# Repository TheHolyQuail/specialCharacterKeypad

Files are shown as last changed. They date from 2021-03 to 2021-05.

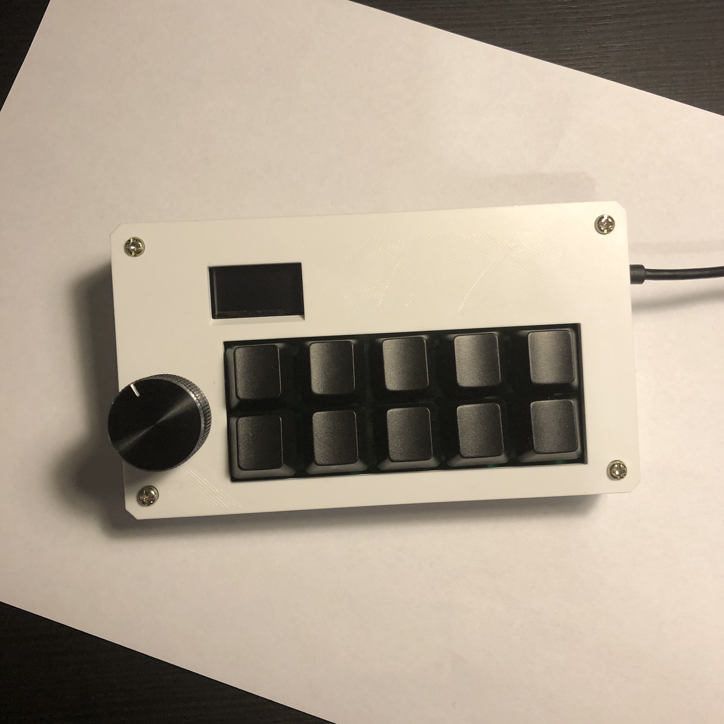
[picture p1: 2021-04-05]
images/keypad with white PLA case.jpg

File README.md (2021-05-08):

# specialCharacterKeypad
This project is a custom keypad using 10 Cherry MX keys as input, a potentiometer to change key values, and 128x64 OLED screen based key value readout all powered by the Raspberry Pi Pico. 
It is focused on allowing quick access to common symbols and letters used in math and science that are not present on the standard US keyboard.

The keypad CAD and ECAD were designed in Fusion 360 and the RP2040 is programed in Curcuitpython taking advantage of the libraries: time, busio, board, displayio, adafruit_displayio_ssd1306 (since the OLED used is based on the ssd1306), adafruit_imageload, math, digitalio, usb_hid, and parts of adafruit_hid.

The custom code is split into two files code.py which contains the loop and keyboard state control and typeSym.py which houses the functions used to send keystrokes to the host computer.

More a more detailed descriptions and assembly/programming instructions are availible on maker.io (link: https://www.digikey.com/en/maker/projects/multifunction-programmable-keypad-made-with-rp2040/5fb464c75f3c4db2a58f450f1997c600)

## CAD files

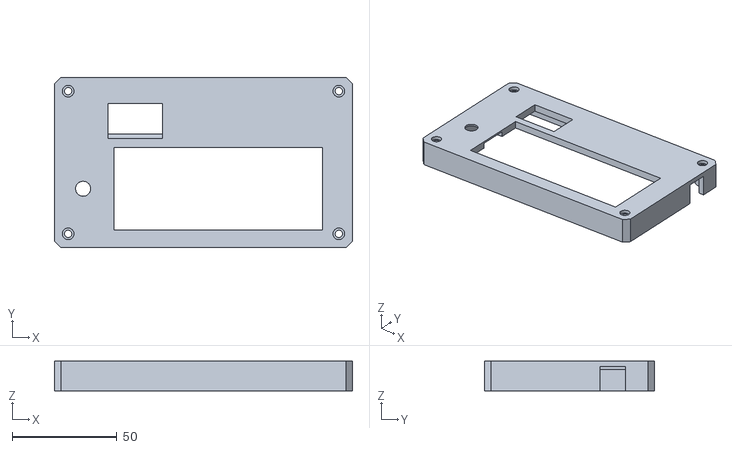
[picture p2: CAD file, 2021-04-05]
3D printable files/shell top V2.stl
142.0 x 81.0 x 14.1

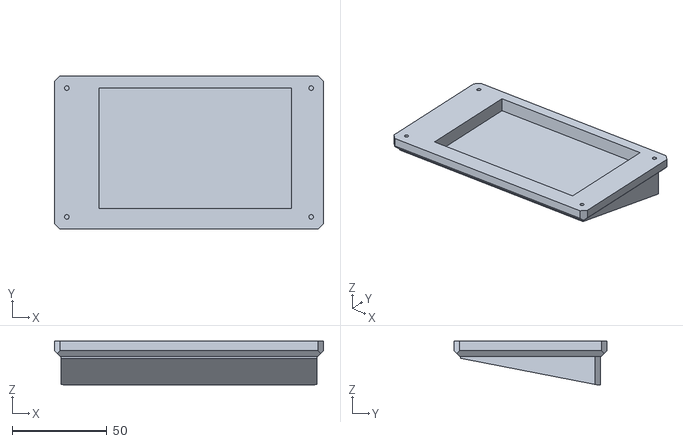
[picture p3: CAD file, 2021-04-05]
3D printable files/shell bottom V2.stl
142.0 x 81.0 x 23.0

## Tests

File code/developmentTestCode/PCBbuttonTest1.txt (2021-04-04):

# libraries for display and pin control
import os
import time
import busio
import board
import displayio
import terminalio
import adafruit_displayio_ssd1306
import adafruit_imageload

# libraries for USB HID
import digitalio
import usb_hid
from adafruit_hid.keyboard import Keyboard
from adafruit_hid.keycode import Keycode
from adafruit_hid.keyboard_layout_us import KeyboardLayoutUS

# library for potentiometer
import analogio

### keyboard and button setup ##############################
# creating keyboard
Keyboard = Keyboard(usb_hid.devices)
Layout = KeyboardLayoutUS(Keyboard)

# declaring button pins
btn0_pin = board.GP15
btn1_pin = board.GP5
btn2_pin = board.GP4
btn3_pin = board.GP3
btn4_pin = board.GP2
btn5_pin = board.GP14
btn6_pin = board.GP13
btn7_pin = board.GP12
btn8_pin = board.GP11
btn9_pin = board.GP10

# setting pin settings
btn0 = digitalio.DigitalInOut(btn0_pin)
btn0.direction = digitalio.Direction.INPUT
btn0.pull = digitalio.Pull.UP

btn1 = digitalio.DigitalInOut(btn1_pin)
btn1.direction = digitalio.Direction.INPUT
btn1.pull = digitalio.Pull.UP

btn2 = digitalio.DigitalInOut(btn2_pin)
btn2.direction = digitalio.Direction.INPUT
btn2.pull = digitalio.Pull.UP

btn3 = digitalio.DigitalInOut(btn3_pin)
btn3.direction = digitalio.Direction.INPUT
btn3.pull = digitalio.Pull.UP

btn4 = digitalio.DigitalInOut(btn4_pin)
btn4.direction = digitalio.Direction.INPUT
btn4.pull = digitalio.Pull.UP

btn5 = digitalio.DigitalInOut(btn5_pin)
btn5.direction = digitalio.Direction.INPUT
btn5.pull = digitalio.Pull.UP

btn6 = digitalio.DigitalInOut(btn6_pin)
btn6.direction = digitalio.Direction.INPUT
btn6.pull = digitalio.Pull.UP

btn7 = digitalio.DigitalInOut(btn7_pin)
btn7.direction = digitalio.Direction.INPUT
btn7.pull = digitalio.Pull.UP

btn8 = digitalio.DigitalInOut(btn8_pin)
btn8.direction = digitalio.Direction.INPUT
btn8.pull = digitalio.Pull.UP

btn9 = digitalio.DigitalInOut(btn9_pin)
btn9.direction = digitalio.Direction.INPUT
btn9.pull = digitalio.Pull.UP

### potentiometer setup ####################################
pot = analogio.AnalogIn(board.GP26)

def get_voltage(pin):
    #return (pin.value * 3.3) / 65536
    return (pin.value)/100

### display setup ##########################################
WIDTH = 128
HEIGHT = 64
CENTER_X = int(WIDTH/2)
CENTER_Y = int(HEIGHT/2)

displayio.release_displays()

SDA = board.GP8
SCL = board.GP9
i2c = busio.I2C(SCL, SDA)

if(i2c.try_lock()):
    print("i2c.scan(): " + str(i2c.scan()))
    i2c.unlock()
print()

display_bus = displayio.I2CDisplay(i2c, device_address=60)
display = adafruit_displayio_ssd1306.SSD1306(display_bus, width=WIDTH, height=HEIGHT)

"""
“displayio” drivers will also work with CircuitPython to display error messages
and other output to the display when the user code is not using it.
"""
print("Raspberry Pi Pico/CircuitPython ")
print("SSD1306 displayio (adafruit_displayio_ssd1306)")
time.sleep(.5)

#print((get_voltage(pot)))
#time.sleep(.5)

#================================================
"""
bitmap1, palette = adafruit_imageload.load("/bitmaps/bitmapTest2.bmp",
                                         bitmap=displayio.Bitmap,
                                         palette=displayio.Palette)
bitmap2, palette = adafruit_imageload.load("/bitmaps/cp_sprite_sheet.bmp",
                                         bitmap=displayio.Bitmap,
                                         palette=displayio.Palette)
"""
# 0:, 1:, 2:, 3:, 4:, 5:, 6:, 7:, 8:, 9:
arrows, palette = adafruit_imageload.load("/bitmaps/arrows.bmp",
                                         bitmap=displayio.Bitmap,
                                         palette=displayio.Palette)

# 0:, 1:, 2:, 3:, 4:, 5:, 6:, 7:, 8:, 9:
logic1, palette = adafruit_imageload.load("/bitmaps/logicSymbols1.bmp",
                                         bitmap=displayio.Bitmap,
                                         palette=displayio.Palette)

# 0:, 1:, 2:, 3:, 4:, 5:, 6:, 7:, 8:, 9:
logic2, palette = adafruit_imageload.load("/bitmaps/logicSymbols2.bmp",
                                         bitmap=displayio.Bitmap,
                                         palette=displayio.Palette)

# 0:, 1:, 2:, 3:, 4:, 5:, 6:, 7:, 8:, 9:
mathOperators1, palette = adafruit_imageload.load("/bitmaps/mathCommonOperators1.bmp",
                                         bitmap=displayio.Bitmap,
                                         palette=displayio.Palette)

# 0:, 1:, 2:, 3:, 4:, 5:, 6:, 7:, 8:, 9:
mathSymbols1, palette = adafruit_imageload.load("/bitmaps/mathCommonSymbols1.bmp",
                                         bitmap=displayio.Bitmap,
                                         palette=displayio.Palette)

# 0:, 1:, 2:, 3:, 4:, 5:, 6:, 7:, 8:, 9:
mathSymbols2, palette = adafruit_imageload.load("/bitmaps/mathCommonSymbols2.bmp",
                                         bitmap=displayio.Bitmap,
                                         palette=displayio.Palette)

# Create a TileGrid to hold the bitmap
#tile_grid1 = displayio.TileGrid(bitmap1, pixel_shader=palette)
#tile_grid2 = displayio.TileGrid(bitmap2, pixel_shader=palette)

arrowsGrid = displayio.TileGrid(arrows, pixel_shader=palette)
logicGrid1 = displayio.TileGrid(logic1, pixel_shader=palette)
logicGrid2 = displayio.TileGrid(logic2, pixel_shader=palette)
mOperatorGrid = displayio.TileGrid(mathOperators1, pixel_shader=palette)
mSymbolGrid1 = displayio.TileGrid(mathSymbols1, pixel_shader=palette)
mSymbolGrid2 = displayio.TileGrid(mathSymbols2, pixel_shader=palette)

# Create a Group to hold the TileGrid
group = displayio.Group(max_size=5)

# Add the TileGrid to the Group
#group.append(tile_grid2)
group.append(arrowsGrid)

# Add the Group to the Display
display.show(group)

# Loop forever so you can enjoy your image
while True:
    time.sleep(0.1)
    if not btn0.value:
        # type "aa"
        Keyboard.press(Keycode.A)
        time.sleep(0.1)
        Keyboard.release(Keycode.A)
        time.sleep(0.1)
        Keyboard.press(Keycode.A)
        time.sleep(0.1)
        Keyboard.release(Keycode.A)
        
    if not btn1.value:
        # type "a"
        Keyboard.press(Keycode.A)
        time.sleep(0.1)
        Keyboard.release(Keycode.A)
        # change display to bitmap one
        group.pop(0)
        group.append(logicGrid1)
        display.show(group)
        #print((get_voltage(pot)))
        
    if not btn2.value:
        # type "∞"
        Keyboard.press(Keycode.ALT, Keycode.KEYPAD_TWO, Keycode.KEYPAD_THREE, Keycode.KEYPAD_SIX)
        time.sleep(0.1)
        Keyboard.release(Keycode.ALT, Keycode.KEYPAD_TWO, Keycode.KEYPAD_THREE, Keycode.KEYPAD_SIX)
        
        # change display to bitmap two
        group.pop(0)
        group.append(logicGrid2)
        display.show(group)
        
    if not btn3.value:
        # type "b"
        Keyboard.press(Keycode.B)
        time.sleep(0.1)
        Keyboard.release(Keycode.B)
        
    if not btn4.value:
        # type "c"
        Keyboard.press(Keycode.C)
        time.sleep(0.1)
        Keyboard.release(Keycode.C)
        
    if not btn5.value:
        # type "d"
        Keyboard.press(Keycode.D)
        time.sleep(0.1)
        Keyboard.release(Keycode.D)
        
    if not btn6.value:
        # type "e"
        Keyboard.press(Keycode.E)
        time.sleep(0.1)
        Keyboard.release(Keycode.E)
        
    if not btn7.value:
        # type "f"
        Keyboard.press(Keycode.F)
        time.sleep(0.1)
        Keyboard.release(Keycode.F)
        
    if not btn8.value:
        # type "g"
        Keyboard.press(Keycode.G)
        time.sleep(0.1)
        Keyboard.release(Keycode.G)
        
    if not btn9.value:
        # type "h"
        Keyboard.press(Keycode.H)
        time.sleep(0.1)
        Keyboard.release(Keycode.H)

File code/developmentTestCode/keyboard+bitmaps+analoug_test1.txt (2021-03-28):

# libraries for display and pin control
import os
import time
import busio
import board
import displayio
import terminalio
import adafruit_displayio_ssd1306
import adafruit_imageload

# libraries for USB HID
import digitalio
import usb_hid
from adafruit_hid.keyboard import Keyboard
from adafruit_hid.keycode import Keycode
from adafruit_hid.keyboard_layout_us import KeyboardLayoutUS

# library for potentiometer
import analogio

### keyboard and button setup ##############################
Keyboard = Keyboard(usb_hid.devices)
Layout = KeyboardLayoutUS(Keyboard)

btn1_pin = board.GP14

btn1 = digitalio.DigitalInOut(btn1_pin)
btn1.direction = digitalio.Direction.INPUT
btn1.pull = digitalio.Pull.DOWN

btn2_pin = board.GP15

btn2 = digitalio.DigitalInOut(btn2_pin)
btn2.direction = digitalio.Direction.INPUT
btn2.pull = digitalio.Pull.DOWN

### potentiometer setup ####################################
pot = analogio.AnalogIn(board.GP26)

def get_voltage(pin):
    #return (pin.value * 3.3) / 65536
    return (pin.value)/100

### display setup ##########################################
WIDTH = 128
HEIGHT = 64
CENTER_X = int(WIDTH/2)
CENTER_Y = int(HEIGHT/2)

displayio.release_displays()

SDA = board.GP8
SCL = board.GP9
i2c = busio.I2C(SCL, SDA)

if(i2c.try_lock()):
    print("i2c.scan(): " + str(i2c.scan()))
    i2c.unlock()
print()

display_bus = displayio.I2CDisplay(i2c, device_address=60)
display = adafruit_displayio_ssd1306.SSD1306(display_bus, width=WIDTH, height=HEIGHT)

"""
“displayio” drivers will also work with CircuitPython to display error messages
and other output to the display when the user code is not using it.
"""
print("Raspberry Pi Pico/CircuitPython ")
print("SSD1306 displayio (adafruit_displayio_ssd1306)")
time.sleep(.5)

#================================================
"""
bitmap1, palette = adafruit_imageload.load("/bitmaps/bitmapTest2.bmp",
                                         bitmap=displayio.Bitmap,
                                         palette=displayio.Palette)
bitmap2, palette = adafruit_imageload.load("/bitmaps/cp_sprite_sheet.bmp",
                                         bitmap=displayio.Bitmap,
                                         palette=displayio.Palette)
"""
# 0:, 1:, 2:, 3:, 4:, 5:, 6:, 7:, 8:, 9:
arrows, palette = adafruit_imageload.load("/bitmaps/arrows.bmp",
                                         bitmap=displayio.Bitmap,
                                         palette=displayio.Palette)

# 0:, 1:, 2:, 3:, 4:, 5:, 6:, 7:, 8:, 9:
logic1, palette = adafruit_imageload.load("/bitmaps/logicSymbols1.bmp",
                                         bitmap=displayio.Bitmap,
                                         palette=displayio.Palette)

# 0:, 1:, 2:, 3:, 4:, 5:, 6:, 7:, 8:, 9:
logic2, palette = adafruit_imageload.load("/bitmaps/logicSymbols2.bmp",
                                         bitmap=displayio.Bitmap,
                                         palette=displayio.Palette)

# 0:, 1:, 2:, 3:, 4:, 5:, 6:, 7:, 8:, 9:
mathOperators1, palette = adafruit_imageload.load("/bitmaps/mathCommonOperators1.bmp",
                                         bitmap=displayio.Bitmap,
                                         palette=displayio.Palette)

# 0:, 1:, 2:, 3:, 4:, 5:, 6:, 7:, 8:, 9:
mathSymbols1, palette = adafruit_imageload.load("/bitmaps/mathCommonSymbols1.bmp",
                                         bitmap=displayio.Bitmap,
                                         palette=displayio.Palette)

# 0:, 1:, 2:, 3:, 4:, 5:, 6:, 7:, 8:, 9:
mathSymbols2, palette = adafruit_imageload.load("/bitmaps/mathCommonSymbols2.bmp",
                                         bitmap=displayio.Bitmap,
                                         palette=displayio.Palette)

# Create a TileGrid to hold the bitmap
#tile_grid1 = displayio.TileGrid(bitmap1, pixel_shader=palette)
#tile_grid2 = displayio.TileGrid(bitmap2, pixel_shader=palette)

arrowsGrid = displayio.TileGrid(arrows, pixel_shader=palette)
logicGrid1 = displayio.TileGrid(logic1, pixel_shader=palette)
logicGrid2 = displayio.TileGrid(logic2, pixel_shader=palette)
mOperatorGrid = displayio.TileGrid(mathOperators1, pixel_shader=palette)
mSymbolGrid1 = displayio.TileGrid(mathSymbols1, pixel_shader=palette)
mSymbolGrid2 = displayio.TileGrid(mathSymbols2, pixel_shader=palette)

# Create a Group to hold the TileGrid
group = displayio.Group(max_size=5)

# Add the TileGrid to the Group
#group.append(tile_grid2)
group.append(arrowsGrid)

# Add the Group to the Display
display.show(group)
print("hi!")
# Loop forever so you can enjoy your image
while True:
    time.sleep(0.1)
    if btn1.value:
        #print("button 1 pressed")
        Keyboard.press(Keycode.A)
        time.sleep(0.1)
        Keyboard.release(Keycode.A)
        # change display to bitmap one
        group.pop(0)
        group.append(logicGrid1)
        display.show(group)
        #print((get_voltage(pot)))
    if btn2.value:
        #print("button 2 pressed")
        #print((get_voltage(adc)),)
        Keyboard.press(Keycode.ALT, Keycode.KEYPAD_TWO, Keycode.KEYPAD_THREE, Keycode.KEYPAD_SIX)
        time.sleep(0.1)
        Keyboard.release(Keycode.KEYPAD_TWO, Keycode.KEYPAD_THREE, Keycode.KEYPAD_SIX, Keycode.ALT)
        
        Keyboard.press(Keycode.ALT, Keycode.KEYPAD_TWO, Keycode.KEYPAD_THREE, Keycode.KEYPAD_SIX)
        time.sleep(0.1)
        Keyboard.release(Keycode.KEYPAD_TWO, Keycode.KEYPAD_THREE, Keycode.KEYPAD_SIX, Keycode.ALT)
        
        Keyboard.press(Keycode.ALT, Keycode.KEYPAD_TWO, Keycode.KEYPAD_THREE, Keycode.KEYPAD_SIX)
        time.sleep(0.1)
        Keyboard.release(Keycode.KEYPAD_TWO, Keycode.KEYPAD_THREE, Keycode.KEYPAD_SIX, Keycode.ALT)
        
        # change display to bitmap two
        group.pop(0)
        group.append(logicGrid2)
        display.show(group)

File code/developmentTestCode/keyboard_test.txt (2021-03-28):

"""CircuitPython Keyboard test"""
import time
import digitalio
import board

import usb_hid
from adafruit_hid.keyboard import Keyboard
from adafruit_hid.keycode import Keycode
from adafruit_hid.keyboard_layout_us import KeyboardLayoutUS

#from machine import ADC, Pina
import analogio

#adc = analogio.AnalogIn(board.GP26)

def get_voltage(pin):
    #return (pin.value * 3.3) / 65536
    return (pin.value)/100

Keyboard = Keyboard(usb_hid.devices)
Layout = KeyboardLayoutUS(Keyboard)

btn1_pin = board.GP14

btn1 = digitalio.DigitalInOut(btn1_pin)
btn1.direction = digitalio.Direction.INPUT
btn1.pull = digitalio.Pull.DOWN

btn2_pin = board.GP15

btn2 = digitalio.DigitalInOut(btn2_pin)
btn2.direction = digitalio.Direction.INPUT
btn2.pull = digitalio.Pull.DOWN

while True:
    if btn1.value:
        print("button 1 pressed")
        Keyboard.press(Keycode.A)
        time.sleep(0.1)
        Keyboard.release(Keycode.A)
    if btn2.value:
        print("button 2 pressed")
        #print((get_voltage(adc)),)
        Keyboard.press(Keycode.ALT, Keycode.KEYPAD_TWO, Keycode.KEYPAD_THREE, Keycode.KEYPAD_SIX)
        time.sleep(0.1)
        Keyboard.release(Keycode.KEYPAD_TWO, Keycode.KEYPAD_THREE, Keycode.KEYPAD_SIX, Keycode.ALT)
        
        Keyboard.press(Keycode.ALT, Keycode.KEYPAD_TWO, Keycode.KEYPAD_THREE, Keycode.KEYPAD_SIX)
        time.sleep(0.1)
        Keyboard.release(Keycode.KEYPAD_TWO, Keycode.KEYPAD_THREE, Keycode.KEYPAD_SIX, Keycode.ALT)
        
        Keyboard.press(Keycode.ALT, Keycode.KEYPAD_TWO, Keycode.KEYPAD_THREE, Keycode.KEYPAD_SIX)
        time.sleep(0.1)
        Keyboard.release(Keycode.KEYPAD_TWO, Keycode.KEYPAD_THREE, Keycode.KEYPAD_SIX, Keycode.ALT)
    time.sleep(0.1)

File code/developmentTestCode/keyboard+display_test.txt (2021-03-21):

"""
Note: this code requires two bitmap files with the file paths /bitmapTest2.bmp and /cp_sprite_sheet.bmp in order to work. (This can be modified in the display setup section)
"""
# libraries for display and pin control
import os
import time
import busio
import board
import displayio
import terminalio
import adafruit_displayio_ssd1306
import adafruit_imageload

# libraries for USB HID
import digitalio
import usb_hid
from adafruit_hid.keyboard import Keyboard
from adafruit_hid.keycode import Keycode
from adafruit_hid.keyboard_layout_us import KeyboardLayoutUS

### keyboard and button setup ##############################
Keyboard = Keyboard(usb_hid.devices)
Layout = KeyboardLayoutUS(Keyboard)

btn1_pin = board.GP14

btn1 = digitalio.DigitalInOut(btn1_pin)
btn1.direction = digitalio.Direction.INPUT
btn1.pull = digitalio.Pull.DOWN

btn2_pin = board.GP15

btn2 = digitalio.DigitalInOut(btn2_pin)
btn2.direction = digitalio.Direction.INPUT
btn2.pull = digitalio.Pull.DOWN

### display setup ##########################################
WIDTH = 128
HEIGHT = 64
CENTER_X = int(WIDTH/2)
CENTER_Y = int(HEIGHT/2)

displayio.release_displays()

SDA = board.GP8
SCL = board.GP9
i2c = busio.I2C(SCL, SDA)

if(i2c.try_lock()):
    print("i2c.scan(): " + str(i2c.scan()))
    i2c.unlock()
print()

display_bus = displayio.I2CDisplay(i2c, device_address=60)
display = adafruit_displayio_ssd1306.SSD1306(display_bus, width=WIDTH, height=HEIGHT)

"""
“displayio” drivers will also work with CircuitPython to display error messages
and other output to the display when the user code is not using it.
"""
print("Raspberry Pi Pico/CircuitPython ")
print("SSD1306 displayio (adafruit_displayio_ssd1306)")
time.sleep(.5)

#================================================
bitmap1, palette = adafruit_imageload.load("/bitmapTest2.bmp",
                                         bitmap=displayio.Bitmap,
                                         palette=displayio.Palette)
bitmap2, palette = adafruit_imageload.load("/cp_sprite_sheet.bmp",
                                         bitmap=displayio.Bitmap,
                                         palette=displayio.Palette)

# Create a TileGrid to hold the bitmap
tile_grid1 = displayio.TileGrid(bitmap1, pixel_shader=palette)
tile_grid2 = displayio.TileGrid(bitmap2, pixel_shader=palette)

# Create a Group to hold the TileGrid
group = displayio.Group(max_size=5)

# Add the TileGrid to the Group
#group.append(tile_grid2)
group.append(tile_grid1)

# Add the Group to the Display
display.show(group)

# Loop forever so you can enjoy your image
while True:
    time.sleep(0.1)
    if btn1.value:
        print("button 1 pressed")
        Keyboard.press(Keycode.A)
        time.sleep(0.1)
        Keyboard.release(Keycode.A)
        # change display to bitmap one
        group.pop(0)
        group.append(tile_grid1)
        display.show(group)
    if btn2.value:
        print("button 2 pressed")
        #print((get_voltage(adc)),)
        Keyboard.press(Keycode.ALT, Keycode.KEYPAD_TWO, Keycode.KEYPAD_THREE, Keycode.KEYPAD_SIX)
        time.sleep(0.1)
        Keyboard.release(Keycode.KEYPAD_TWO, Keycode.KEYPAD_THREE, Keycode.KEYPAD_SIX, Keycode.ALT)
        
        Keyboard.press(Keycode.ALT, Keycode.KEYPAD_TWO, Keycode.KEYPAD_THREE, Keycode.KEYPAD_SIX)
        time.sleep(0.1)
        Keyboard.release(Keycode.KEYPAD_TWO, Keycode.KEYPAD_THREE, Keycode.KEYPAD_SIX, Keycode.ALT)
        
        Keyboard.press(Keycode.ALT, Keycode.KEYPAD_TWO, Keycode.KEYPAD_THREE, Keycode.KEYPAD_SIX)
        time.sleep(0.1)
        Keyboard.release(Keycode.KEYPAD_TWO, Keycode.KEYPAD_THREE, Keycode.KEYPAD_SIX, Keycode.ALT)
        
        # change display to bitmap two
        group.pop(0)
        group.append(tile_grid2)
        display.show(group)

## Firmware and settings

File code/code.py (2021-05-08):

# libraries for display and pin control
# import os
import time
import busio
import board
import displayio
# import terminalio
import adafruit_displayio_ssd1306
import adafruit_imageload
import math

# libraries for USB HID
import digitalio
import usb_hid
from adafruit_hid.keyboard import Keyboard
# from adafruit_hid.keycode import Keycode
from adafruit_hid.keyboard_layout_us import KeyboardLayoutUS

# custom library for typing special characters
from typeSym import (type_arrowUp, type_arrowDown, type_arrowUpDown
                     , type_oneHalf, type_squared, type_arrowRight
                     , type_arrowLeft, type_arrowRightLeft, type_ae
                     , type_degree, type_lowerTao, type_lowerBeta
                     , type_lowerSigma, type_lowerPhi, type_lowerDelta
                     , type_thorn, type_infinity, type_pi
                     , type_lowerMu, type_capitalOmega, type_capitalSigma
                     , type_theta, type_upperPhi, type_lowerEpsilon
                     , type_lowerAlpha, type_plusMinus, type_aproxEqual
                     , type_greaterOrEqual, type_lesserOrEqual, type_implies
                     , type_squareRoot, type_notEqual, type_oOperator
                     , type_dotProduct, type_defineEqual, type_intersection
                     , type_union, type_parallel, type_notParallel
                     , type_perpendicular, type_not, type_proves
                     , type_emptySet, type_bold, type_italic
                     , type_pageBreak, type_pasteNoFormat, type_subscript
                     , type_shortcutList, type_strikethrough, type_insertFootnote
                     , type_insertComment, type_superscript, unicodeSearch
                     , openPowershell, openSnipSketch, type_parentheses
                     , type_curllyBrackets, type_squareBrackets, type_doubleQuotes
                     , type_singleQuotes, type_commaSpace, unTab, commentCode)


# library for potentiometer
import analogio

# keyboard and button setup ##############################
# creating keyboard
Keyboard = Keyboard(usb_hid.devices)
Layout = KeyboardLayoutUS(Keyboard)

# declaring button pins
btn0_pin = board.GP15
btn1_pin = board.GP5
btn2_pin = board.GP4
btn3_pin = board.GP3
btn4_pin = board.GP2
btn5_pin = board.GP14
btn6_pin = board.GP13
btn7_pin = board.GP12
btn8_pin = board.GP11
btn9_pin = board.GP10

# setting pin settings
btn0 = digitalio.DigitalInOut(btn0_pin)
btn0.direction = digitalio.Direction.INPUT
btn0.pull = digitalio.Pull.UP

btn1 = digitalio.DigitalInOut(btn1_pin)
btn1.direction = digitalio.Direction.INPUT
btn1.pull = digitalio.Pull.UP

btn2 = digitalio.DigitalInOut(btn2_pin)
btn2.direction = digitalio.Direction.INPUT
btn2.pull = digitalio.Pull.UP

btn3 = digitalio.DigitalInOut(btn3_pin)
btn3.direction = digitalio.Direction.INPUT
btn3.pull = digitalio.Pull.UP

btn4 = digitalio.DigitalInOut(btn4_pin)
btn4.direction = digitalio.Direction.INPUT
btn4.pull = digitalio.Pull.UP

btn5 = digitalio.DigitalInOut(btn5_pin)
btn5.direction = digitalio.Direction.INPUT
btn5.pull = digitalio.Pull.UP

btn6 = digitalio.DigitalInOut(btn6_pin)
btn6.direction = digitalio.Direction.INPUT
btn6.pull = digitalio.Pull.UP

btn7 = digitalio.DigitalInOut(btn7_pin)
btn7.direction = digitalio.Direction.INPUT
btn7.pull = digitalio.Pull.UP

btn8 = digitalio.DigitalInOut(btn8_pin)
btn8.direction = digitalio.Direction.INPUT
btn8.pull = digitalio.Pull.UP

btn9 = digitalio.DigitalInOut(btn9_pin)
btn9.direction = digitalio.Direction.INPUT
btn9.pull = digitalio.Pull.UP

# potentiometer setup ####################################
pot = analogio.AnalogIn(board.GP26)
potPosition = 0
previousPotPosition = 0

def get_voltage(pin):
    # return (pin.value * 3.3) / 65536
    return (pin.value)/100

potValue = get_voltage(pot)

# character typing function setup ########################
"""
def type_a():
    Keyboard.press(Keycode.A)
    time.sleep(0.1)Θ
    Keyboard.release(Keycode.A)
"""
currentBitmap = 0

# display setup ##########################################
WIDTH = 128
HEIGHT = 64
CENTER_X = int(WIDTH/2)
CENTER_Y = int(HEIGHT/2)

displayio.release_displays()

SDA = board.GP8
SCL = board.GP9
i2c = busio.I2C(SCL, SDA)

if(i2c.try_lock()):
    print("i2c.scan(): " + str(i2c.scan()))
    i2c.unlock()
print()

display_bus = displayio.I2CDisplay(i2c, device_address=60)
display = adafruit_displayio_ssd1306.SSD1306(display_bus, width=WIDTH, height=HEIGHT)

"""
“displayio” drivers will also work with CircuitPython to display error messages
and other output to the display when the user code is not using it.
"""
print("Raspberry Pi Pico/CircuitPython ")
print("SSD1306 displayio (adafruit_displayio_ssd1306)")
time.sleep(.1)

# ================================================
"""
bitmap1, palette = adafruit_imageload.load("/bitmaps/bitmapTest2.bmp",
                                         bitmap=displayio.Bitmap,
                                         palette=displayio.Palette)
"""
# 0:, 1:, 2:, 3:, 4:, 5:, 6:, 7:, 8:, 9:
arrows, palette = adafruit_imageload.load("/bitmaps/arrows.bmp",
                                          bitmap=displayio.Bitmap,
                                          palette=displayio.Palette)

# 0:, 1:, 2:, 3:, 4:, 5:, 6:, 7:, 8:, 9:
logic1, palette = adafruit_imageload.load("/bitmaps/logicSymbols1.bmp",
                                          bitmap=displayio.Bitmap,
                                          palette=displayio.Palette)

# 0:, 1:, 2:, 3:, 4:, 5:, 6:, 7:, 8:, 9:
logic2, palette = adafruit_imageload.load("/bitmaps/logicSymbols2.bmp",
                                          bitmap=displayio.Bitmap,
                                          palette=displayio.Palette)

# 0:, 1:, 2:, 3:, 4:, 5:, 6:, 7:, 8:, 9:
mathOperators1, palette = adafruit_imageload.load("/bitmaps/mathCommonOperators1.bmp",
                                                  bitmap=displayio.Bitmap,
                                                  palette=displayio.Palette)

# 0:, 1:, 2:, 3:, 4:, 5:, 6:, 7:, 8:, 9:
mathSymbols1, palette = adafruit_imageload.load("/bitmaps/mathCommonSymbols1.bmp",
                                                bitmap=displayio.Bitmap,
                                                palette=displayio.Palette)

# 0:, 1:, 2:, 3:, 4:, 5:, 6:, 7:, 8:, 9:
mathSymbols2, palette = adafruit_imageload.load("/bitmaps/mathCommonSymbols2.bmp",
                                                bitmap=displayio.Bitmap,
                                                palette=displayio.Palette)

# 0:, 1:, 2:, 3:, 4:, 5:, 6:, 7:, 8:, 9:
gDocShortcuts, palette = adafruit_imageload.load("/bitmaps/gDocShortcuts.bmp",
                                                 bitmap=displayio.Bitmap,
                                                 palette=displayio.Palette)

# 0:, 1:, 2:, 3:, 4:, 5:, 6:, 7:, 8:, 9:
code1, palette = adafruit_imageload.load("/bitmaps/code1.bmp",
                                                 bitmap=displayio.Bitmap,
                                                 palette=displayio.Palette)

# Create TileGrids to hold the bitmaps
# tile_grid1 = displayio.TileGrid(bitmap1, pixel_shader=palette)

arrowsGrid = displayio.TileGrid(arrows, pixel_shader=palette)
logicGrid1 = displayio.TileGrid(logic1, pixel_shader=palette)
logicGrid2 = displayio.TileGrid(logic2, pixel_shader=palette)
mOperatorGrid1 = displayio.TileGrid(mathOperators1, pixel_shader=palette)
mSymbolGrid1 = displayio.TileGrid(mathSymbols1, pixel_shader=palette)
mSymbolGrid2 = displayio.TileGrid(mathSymbols2, pixel_shader=palette)
gDocShortGrid = displayio.TileGrid(gDocShortcuts, pixel_shader=palette)
codeGrid1 = displayio.TileGrid(code1, pixel_shader=palette)

# Create a Group to hold the TileGrids
group = displayio.Group(max_size=5)

# Add the TileGrid to the Group
# group.append(tile_grid2)
group.append(arrowsGrid)

# Add the Group to the Display
display.show(group)

# Loop forever so you can enjoy your image
while True:
    time.sleep(0.1)

    # check potentiometer and update position (potentiometer values range from ~10 to ~640)
    if math.fabs(get_voltage(pot) - potValue) > 10:
        potValue = get_voltage(pot)

        if get_voltage(pot) > 608:
            # set keyboard to code1
            potPosition = 7

            group.pop(0)
            group.append(codeGrid1)
            display.show(group)
            
        elif get_voltage(pot) > 538:
            # set keyboard to google doc shortcuts
            potPosition = 6

            group.pop(0)
            group.append(gDocShortGrid)
            display.show(group)

        elif get_voltage(pot) > 448:
            # set keyboard to logic symbols 1
            potPosition = 5

            group.pop(0)
            group.append(logicGrid1)
            display.show(group)

        elif get_voltage(pot) > 358:
            # set keyboard to logic symbols 2
            potPosition = 4

            group.pop(0)
            group.append(logicGrid2)
            display.show(group)

        elif get_voltage(pot) > 268:
            # set keyboard to math operators 1
            potPosition = 3

            group.pop(0)
            group.append(mOperatorGrid1)
            display.show(group)

        elif get_voltage(pot) > 178:
            # set keyboard to math symbols 1
            potPosition = 2

            group.pop(0)
            group.append(mSymbolGrid1)
            display.show(group)

        elif get_voltage(pot) > 88:
            # set keyboard to math symbols 2
            potPosition = 1

            group.pop(0)
            group.append(mSymbolGrid2)
            display.show(group)

        else:
            # set keyboard to arrows and exponents
            potPosition = 0

            group.pop(0)
            group.append(arrowsGrid)
            display.show(group)

# ----------------------------------------------------------

    if potPosition == 0:
        if not btn0.value:
            # type "↑"
            type_arrowUp()

        if not btn1.value:
            # type "↓"
            type_arrowDown()

        if not btn2.value:
            # type "↕"
            type_arrowUpDown()

        if not btn3.value:
            # type "½"
            type_oneHalf()

        if not btn4.value:
            # type "²"
            type_squared()

        if not btn5.value:
            # type "→"
            type_arrowRight()

        if not btn6.value:
            # type "←"
            type_arrowLeft()

        if not btn7.value:
            # type "↔"
            type_arrowRightLeft()

        if not btn8.value:
            # type "æ"
            type_ae()

        if not btn9.value:
            # type "°"
            type_degree()

# ----------------------------------------------------------

    elif potPosition == 1:
        if not btn0.value:
            # type ""
            unicodeSearch()

        if not btn1.value:
            # type "τ"
            type_lowerTao()

        if not btn2.value:
            # type ""
            unicodeSearch()

        if not btn3.value:
            # type ""
            unicodeSearch()

        if not btn4.value:
            # type "ß"
            type_lowerBeta()

        if not btn5.value:
            # type "σ"
            type_lowerSigma()

        if not btn6.value:
            # type "φ"
            type_lowerPhi()

        if not btn7.value:
            # type "δ"
            type_lowerDelta()

        if not btn8.value:
            # type ""
            unicodeSearch()

        if not btn9.value:
            # type "Þ"
            type_thorn()

# ----------------------------------------------------------

    elif potPosition == 2:
        if not btn0.value:
            # type "∞"
            type_infinity()

        if not btn1.value:
            # type "π"
            type_pi()

        if not btn2.value:
            # type ""
            unicodeSearch()

        if not btn3.value:
            # type "µ"
            type_lowerMu()

        if not btn4.value:
            # type "Ω"
            type_capitalOmega()

        if not btn5.value:
            # type "Σ"
            type_capitalSigma()

        if not btn6.value:
            # type "Θ"
            type_theta()

        if not btn7.value:
            # type "Φ"
            type_upperPhi()

        if not btn8.value:
            # type "ε"
            type_lowerEpsilon()

        if not btn9.value:
            # type "α"
            type_lowerAlpha()

# ----------------------------------------------------------

    elif potPosition == 3:
        if not btn0.value:
            # type "±"
            type_plusMinus()

        if not btn1.value:
            # type "≈"
            type_aproxEqual()

        if not btn2.value:
            # type "≥"
            type_greaterOrEqual()

        if not btn3.value:
            # type "≤"
            type_lesserOrEqual()

        if not btn4.value:
            # type "═>"
            type_implies()

        if not btn5.value:
            # type "√("
            type_squareRoot()

        if not btn6.value:
            # type "!="
            type_notEqual()

        if not btn7.value:
            # type "○"
            type_oOperator()

        if not btn8.value:
            # type "•"
            type_dotProduct()

        if not btn9.value:
            # type "≡"
            type_defineEqual()

# ----------------------------------------------------------

    elif potPosition == 4:
        if not btn0.value:
            # type "∩"
            type_intersection()

        if not btn1.value:
            # type "U"
            type_union()

        if not btn2.value:
            # type ""
            unicodeSearch()

        if not btn3.value:
            # type ""
            unicodeSearch()

        if not btn4.value:
            # type ""
            unicodeSearch()

        if not btn5.value:
            # type ""
            unicodeSearch()

        if not btn6.value:
            # type ""
            unicodeSearch()

        if not btn7.value:
            # type "||"
            type_parallel()

        if not btn8.value:
            # type "╫"
            type_notParallel()

        if not btn9.value:
            # type "┴"
            type_perpendicular()

# ----------------------------------------------------------

    elif potPosition == 5:
        if not btn0.value:
            # type ""
            unicodeSearch()

        if not btn1.value:
            # type ""
            unicodeSearch()

        if not btn2.value:
            # type ""
            unicodeSearch()

        if not btn3.value:
            # type "¬"
            type_not()

        if not btn4.value:
            # type "├"
            type_proves()

        if not btn5.value:
            # type ""
            unicodeSearch()

        if not btn6.value:
            # type ""
            unicodeSearch()

        if not btn7.value:
            # type ""
            unicodeSearch()

        if not btn8.value:
            # type ""
            unicodeSearch()

        if not btn9.value:
            # type "Ø"
            type_emptySet()

# ----------------------------------------------------------

    elif potPosition == 6:
        if not btn0.value:
            # ctrl+b
            type_bold()

        if not btn1.value:
            # ctrl+i
            type_italic()

        if not btn2.value:
            # t
            type_pageBreak()

        if not btn3.value:
            # t
            type_pasteNoFormat()

        if not btn4.value:
            # t
            type_subscript()

        if not btn5.value:
            # t
            type_shortcutList()

        if not btn6.value:
            # t
            type_strikethrough()

        if not btn7.value:
            # t
            type_insertFootnote()

        if not btn8.value:
            # t
            type_insertComment()

        if not btn9.value:
            # t
            type_superscript()

# ----------------------------------------------------------

    elif potPosition == 7:
        if not btn0.value:
            # type parentheses and back arrow into them.
            type_parentheses()

        if not btn1.value:
            # type curlly brackets and back arrow into them.
            type_curllyBrackets()

        if not btn2.value:
            # type square brackets and back arrow into them.
            type_squareBrackets()

        if not btn3.value:
            # type double quotes and back arrow into them.
            type_doubleQuotes()

        if not btn4.value:
            # type single quotes and back arrow into them.
            type_singleQuotes()

        if not btn5.value:
            # type a comma follwed with a space
            type_commaSpace()

        if not btn6.value:
            # un-tab shortcut
            unTab()

        if not btn7.value:
            # comment code shortcut
            commentCode()

        if not btn8.value:
            # open power shell application
            openPowershell()

        if not btn9.value:
            # open snip and sketch application
            openSnipSketch()

# ---------------------------------------------------

    else:
        if not btn0.value:
            # type "π"
            type_pi()

        if not btn1.value:
            # type "π"
            type_pi()

        if not btn2.value:
            # type "π"
            type_pi()

        if not btn3.value:
            # type "π"
            type_pi()

        if not btn4.value:
            # type "π"
            type_pi()

        if not btn5.value:
            # type "π"
            type_pi()

        if not btn6.value:
            # type "π"
            type_pi()

        if not btn7.value:
            # type "π"
            type_pi()

        if not btn8.value:
            # type "π"
            type_pi()

        if not btn9.value:
            # type "π"
            type_pi()

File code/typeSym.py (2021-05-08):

# importing necessary functions
import time
import usb_hid
from adafruit_hid.keyboard import Keyboard
from adafruit_hid.keycode import Keycode
from adafruit_hid.keyboard_layout_us import KeyboardLayoutUS

# setting up an HID keyboard
Keyboard = Keyboard(usb_hid.devices)
Layout = KeyboardLayoutUS(Keyboard)

# the functions for typing special characters
# test:
def type_a():
    # types: "a"
    Keyboard.press(Keycode.A)
    time.sleep(0.02)
    Keyboard.release(Keycode.A)

# open the unicode search menu if there is no general use alt code
def unicodeSearch():
    Keyboard.press(Keycode.WINDOWS, Keycode.R)
    time.sleep(0.04)
    Keyboard.release(Keycode.WINDOWS, Keycode.R)
    time.sleep(0.02)
    # type "charmap"
    Keyboard.press(Keycode.C)
    time.sleep(0.02)
    Keyboard.release(Keycode.C)
    Keyboard.press(Keycode.H)
    time.sleep(0.02)
    Keyboard.release(Keycode.H)
    Keyboard.press(Keycode.A)
    time.sleep(0.02)
    Keyboard.release(Keycode.A)
    Keyboard.press(Keycode.R)
    time.sleep(0.02)
    Keyboard.release(Keycode.R)
    Keyboard.press(Keycode.M)
    time.sleep(0.02)
    Keyboard.release(Keycode.M)
    Keyboard.press(Keycode.A)
    time.sleep(0.02)
    Keyboard.release(Keycode.A)
    Keyboard.press(Keycode.P)
    time.sleep(0.02)
    Keyboard.release(Keycode.P)
    time.sleep(0.02)
    Keyboard.press(Keycode.ENTER)
    time.sleep(0.02)
    Keyboard.release(Keycode.ENTER)
    time.sleep(0.02)

# arrows
def type_arrowLeft():
    # types: ←
    Keyboard.press(Keycode.ALT)
    time.sleep(0.02)
    Keyboard.press(Keycode.KEYPAD_TWO)
    time.sleep(0.02)
    Keyboard.release(Keycode.KEYPAD_TWO)
    time.sleep(0.02)
    Keyboard.press(Keycode.KEYPAD_SEVEN)
    time.sleep(0.02)
    Keyboard.release(Keycode.KEYPAD_SEVEN)
    time.sleep(0.02)
    Keyboard.release(Keycode.ALT)

def type_arrowRight():
    # types: →
    Keyboard.press(Keycode.ALT)
    time.sleep(0.02)
    Keyboard.press(Keycode.KEYPAD_TWO)
    time.sleep(0.02)
    Keyboard.release(Keycode.KEYPAD_TWO)
    time.sleep(0.02)
    Keyboard.press(Keycode.KEYPAD_SIX)
    time.sleep(0.02)
    Keyboard.release(Keycode.KEYPAD_SIX)
    time.sleep(0.02)
    Keyboard.release(Keycode.ALT)

def type_arrowRightLeft():
    # types: ↔
    Keyboard.press(Keycode.ALT)
    time.sleep(0.02)
    Keyboard.press(Keycode.KEYPAD_TWO)
    time.sleep(0.02)
    Keyboard.release(Keycode.KEYPAD_TWO)
    time.sleep(0.02)
    Keyboard.press(Keycode.KEYPAD_NINE)
    time.sleep(0.02)
    Keyboard.release(Keycode.KEYPAD_NINE)
    time.sleep(0.02)
    Keyboard.release(Keycode.ALT)

def type_arrowUp():
    # types: ↑
    Keyboard.press(Keycode.ALT)
    time.sleep(0.02)
    Keyboard.press(Keycode.KEYPAD_TWO)
    time.sleep(0.02)
    Keyboard.release(Keycode.KEYPAD_TWO)
    time.sleep(0.02)
    Keyboard.press(Keycode.KEYPAD_FOUR)
    time.sleep(0.02)
    Keyboard.release(Keycode.KEYPAD_FOUR)
    time.sleep(0.02)
    Keyboard.release(Keycode.ALT)

def type_arrowDown():
    # types: ↓
    Keyboard.press(Keycode.ALT)
    time.sleep(0.02)
    Keyboard.press(Keycode.KEYPAD_TWO)
    time.sleep(0.02)
    Keyboard.release(Keycode.KEYPAD_TWO)
    time.sleep(0.02)
    Keyboard.press(Keycode.KEYPAD_FIVE)
    time.sleep(0.02)
    Keyboard.release(Keycode.KEYPAD_FIVE)
    time.sleep(0.02)
    Keyboard.release(Keycode.ALT)

def type_arrowUpDown():
    # types: ↕
    Keyboard.press(Keycode.ALT)
    time.sleep(0.02)
    Keyboard.press(Keycode.KEYPAD_ONE)
    time.sleep(0.02)
    Keyboard.release(Keycode.KEYPAD_ONE)
    time.sleep(0.02)
    Keyboard.press(Keycode.KEYPAD_EIGHT)
    time.sleep(0.02)
    Keyboard.release(Keycode.KEYPAD_EIGHT)
    time.sleep(0.02)
    Keyboard.release(Keycode.ALT)

def type_oneHalf():
    # types: ½
    Keyboard.press(Keycode.ALT)
    time.sleep(0.02)
    Keyboard.press(Keycode.KEYPAD_ZERO)
    time.sleep(0.02)
    Keyboard.release(Keycode.KEYPAD_ZERO)
    time.sleep(0.02)
    Keyboard.press(Keycode.KEYPAD_ONE)
    time.sleep(0.02)
    Keyboard.release(Keycode.KEYPAD_ONE)
    time.sleep(0.02)
    Keyboard.press(Keycode.KEYPAD_EIGHT)
    time.sleep(0.02)
    Keyboard.release(Keycode.KEYPAD_EIGHT)
    time.sleep(0.02)
    Keyboard.press(Keycode.KEYPAD_NINE)
    time.sleep(0.02)
    Keyboard.release(Keycode.KEYPAD_NINE)
    time.sleep(0.02)
    Keyboard.release(Keycode.ALT)

def type_ae():
    # types: æ
    Keyboard.press(Keycode.ALT)
    time.sleep(0.02)
    Keyboard.press(Keycode.KEYPAD_ZERO)
    time.sleep(0.02)
    Keyboard.release(Keycode.KEYPAD_ZERO)
    time.sleep(0.02)
    Keyboard.press(Keycode.KEYPAD_TWO)
    time.sleep(0.02)
    Keyboard.release(Keycode.KEYPAD_TWO)
    time.sleep(0.02)
    Keyboard.press(Keycode.KEYPAD_THREE)
    time.sleep(0.02)
    Keyboard.release(Keycode.KEYPAD_THREE)
    time.sleep(0.02)
    Keyboard.press(Keycode.KEYPAD_ZERO)
    time.sleep(0.02)
    Keyboard.release(Keycode.KEYPAD_ZERO)
    time.sleep(0.02)
    Keyboard.release(Keycode.ALT)

def type_degree():
    # types: °
    Keyboard.press(Keycode.ALT)
    time.sleep(0.02)
    Keyboard.press(Keycode.KEYPAD_TWO)
    time.sleep(0.02)
    Keyboard.release(Keycode.KEYPAD_TWO)
    time.sleep(0.02)
    Keyboard.press(Keycode.KEYPAD_FOUR)
    time.sleep(0.02)
    Keyboard.release(Keycode.KEYPAD_FOUR)
    time.sleep(0.02)
    Keyboard.press(Keycode.KEYPAD_EIGHT)
    time.sleep(0.02)
    Keyboard.release(Keycode.KEYPAD_EIGHT)
    time.sleep(0.02)
    Keyboard.release(Keycode.ALT)

def type_squared():
    # types: ²
    Keyboard.press(Keycode.ALT)
    time.sleep(0.02)
    Keyboard.press(Keycode.KEYPAD_ZERO)
    time.sleep(0.02)
    Keyboard.release(Keycode.KEYPAD_ZERO)
    time.sleep(0.02)
    Keyboard.press(Keycode.KEYPAD_ONE)
    time.sleep(0.02)
    Keyboard.release(Keycode.KEYPAD_ONE)
    time.sleep(0.02)
    Keyboard.press(Keycode.KEYPAD_SEVEN)
    time.sleep(0.02)
    Keyboard.release(Keycode.KEYPAD_SEVEN)
    time.sleep(0.02)
    Keyboard.press(Keycode.KEYPAD_EIGHT)
    time.sleep(0.02)
    Keyboard.release(Keycode.KEYPAD_EIGHT)
    time.sleep(0.02)
    Keyboard.release(Keycode.ALT)

# logicSymbols1
# no type_thereExists

# no type_notThereExists

# no type_forAll

def type_not():
    # types: ¬
    Keyboard.press(Keycode.ALT)
    time.sleep(0.02)
    Keyboard.press(Keycode.KEYPAD_ONE)
    time.sleep(0.02)
    Keyboard.release(Keycode.KEYPAD_ONE)
    time.sleep(0.02)
    Keyboard.press(Keycode.KEYPAD_SEVEN)
    time.sleep(0.02)
    Keyboard.release(Keycode.KEYPAD_SEVEN)
    time.sleep(0.02)
    Keyboard.press(Keycode.KEYPAD_ZERO)
    time.sleep(0.02)
    Keyboard.release(Keycode.KEYPAD_ZERO)
    time.sleep(0.02)
    Keyboard.release(Keycode.ALT)
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

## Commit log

2021-03-07 initial commit of ECAD schematic
    [keypad-ECAD.sch]
2021-03-07 add rasperry pi pico library
2021-03-07 add LCD display
    [keypad-ECAD.sch]
2021-03-21 add OLED library and schematic connections
    [keypad-ECAD.sch]
2021-03-21 fix missed button connection
    [keypad-ECAD.sch]
2021-03-21 add PCB gerber files (generated with Fusion 360)
    [copper_bottom.gbr, copper_top.gbr, drill_1_16.xln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]
2021-03-27 add bitmap files and folder
    [copper_bottom.gbr, copper_top.gbr, drill_1_16.xln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]
2021-04-04 add 3D printable STL files
    [shell bottom V1.stl, shell top V1.stl]
2021-04-05 add updated 3D printable STL files
    [shell bottom V2.stl, shell top V2.stl]
2021-05-08 add gerber file with fixed key alignment
2021-05-08 remove old version of case with misalighed potentiometer hole
    [shell bottom V1.stl, shell top V1.stl]
